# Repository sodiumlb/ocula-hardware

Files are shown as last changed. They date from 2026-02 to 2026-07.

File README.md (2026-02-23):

# ocula-hardware
Hardware design files for the Oric OCULA ULA replacement project.

## Related projects
[User Documentation](https://github.com/sodiumlb/ocula-docs)
[Firmware](https://github.com/sodiumlb/ocula-pivic-firmware)

## Important notes
OCULA hardware has been designed for low cost assembled production. It is not recommended to attempt manual assembly of anything other than through-hole components (headers, connectors).

Currently only OCULA-is-the-RAM mode is supported by the firmware, which means 2 mux-bridges are required for normal operation. The Micro DVI adapter and cable is optional.

## Main OCULA PCB
See pcb directory for design files for PCB production and PCBA of all surface mounted components. Due to very low clearance inside Oric-1 and Atmos cases, it is recommended to use stacking pin-headers to create flat pins on OCULA to allow low-profile mounting in machines with sockets.

## Mux bridges
The mux bridges use thin PCBs - 0.6mm is the only tested PCB thickness. The 3D printed snap-on frame will require modification if the PCB is different. The mux bridge modification is extremely simple and other solutions can be created. The effort put into this particular mux bridge design is to allow non-destructive but reliable modification of the Oric most people can use.

The current design is best assembled by first snapping the PCB into the 3D printed frame, then soldering in the 8 required pins. Thin, flat, flexible pins are needed here to make good contact with the mux ICs, thus it is recommended making these from the same stacking pin-headers as for the OCULA pins. Take care not to apply too much heat or use too long time, the 3D printed snap-on-frame will warp easily.

## Micro DVI adapter
The micro DVI adapter is optional. See the dvi-micro-adapter for PCB and 3D print adapter design files. The required cable spec is FFC, 20cm, 20pin, 0.5mm pitch, reverse direction (contacts are on opposing side on each end).

The 3D printed Oric adapter is designed to fit in place of the RF modulator. To secure the adapter, a longer screw is needed in place of the original PCB mounting screw fitted next to the RF modulator.

## Using stacking pin row headers to create IC pins
While there are many options for adding IC pins to PCBs, the solution that has provided the best low-cost way to get close to compatible with original IC pins, is to create them from long pinned PCB stacking headers. These have flat pins in a more spring-like metal that serves this alternative application well. 

This example shows 1x20 row 11mm stacking pin row headers.  
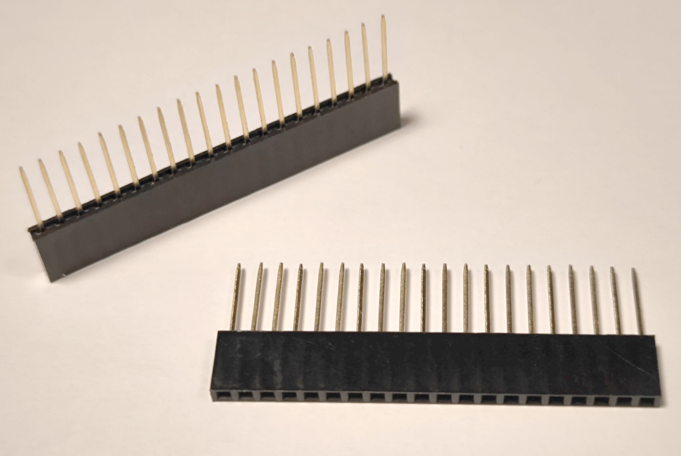
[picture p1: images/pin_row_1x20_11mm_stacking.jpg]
Example stacking pin headers

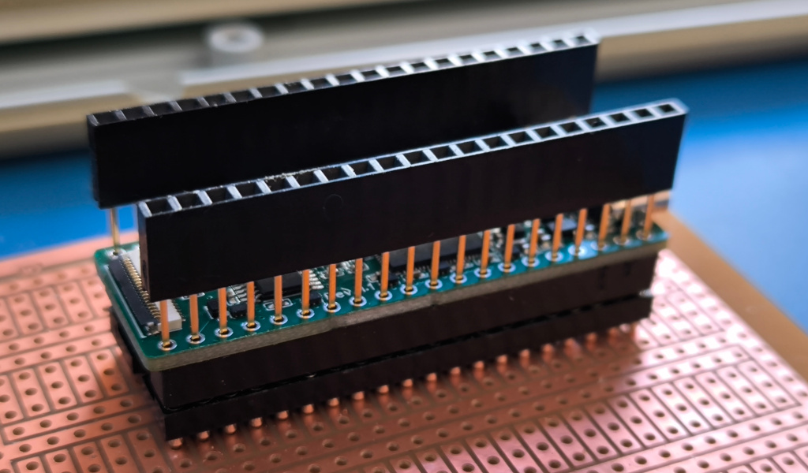
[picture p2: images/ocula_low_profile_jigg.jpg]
OCULA low-profile pin jigg

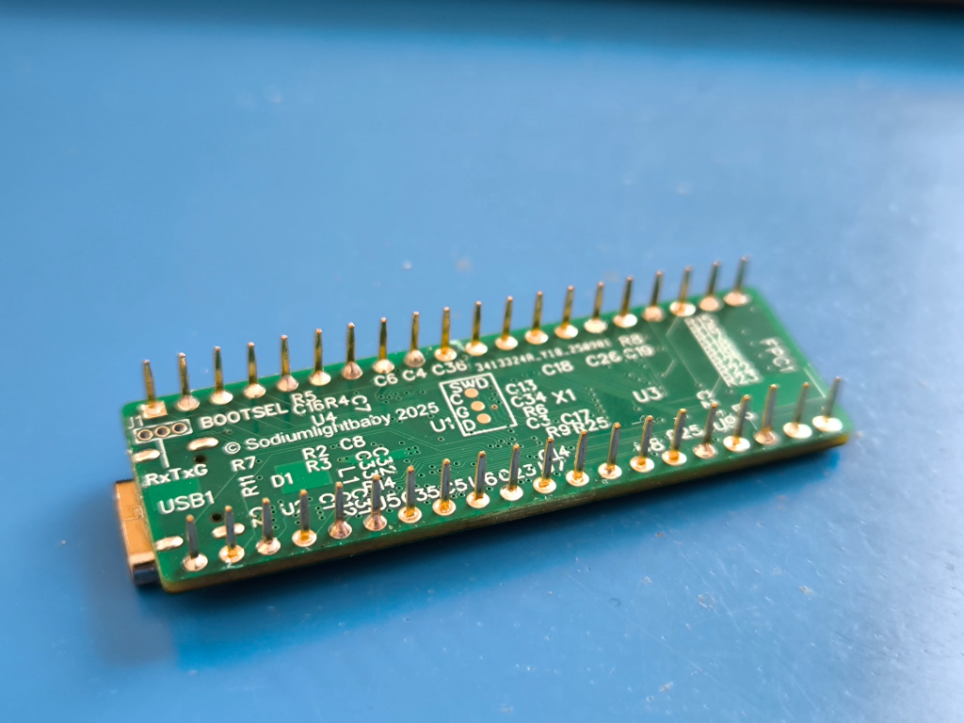
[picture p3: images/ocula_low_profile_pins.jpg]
OCULA low-profile pins

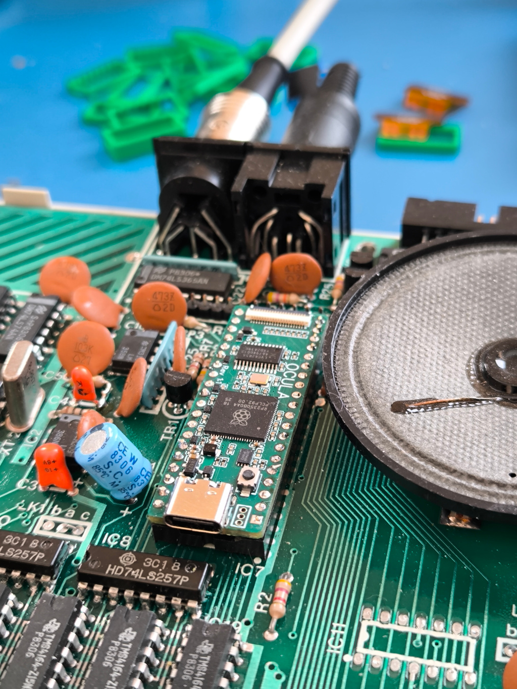
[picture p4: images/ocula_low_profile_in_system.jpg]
OCULA low-profile mounted in system


# Disclaimer
OCULA is an open source project by and for Oric users. It is provided AS-IS. For more information see each sub-project license agreement.

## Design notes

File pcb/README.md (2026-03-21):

# OCULA PCB Notes
The PCB package consists of EasyEDA SCH schematics and PCB board design source files, and Gerber, BOM and PickAndPlace production files for PCBA.

## BOM Notes
The following components are intentionally excluded from the BOM
1. J1 - Serial debug terminal header. Not needed for normal use
2. R4 - Flash pull-up resistor. A 10k pull-up may be needed for different flash chips.
3. IC1 - The ULA DIP-40 pin layout. IC pin substitues (pin-headers) must be installed manually after PCBA.

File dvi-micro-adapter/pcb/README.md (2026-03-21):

# Micro DVI Adapter
This FFC cable adapter is electrically compatible with both OCULA and PIVIC, and physically designed for integration in place of the Oric RF modulator together with the 3D printed adapter.

## BOM Notes
Be ware of additional X-Ray services can be added to the PCBA cost due to the pin placement on the Micro-HDMI style connector.
The alternative BOM with a substitue display connector is provided trading off component cost against service cost.

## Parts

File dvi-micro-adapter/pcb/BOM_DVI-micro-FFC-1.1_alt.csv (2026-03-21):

ID | Name | Designator | Footprint | Quantity | Manufacturer Part | Manufacturer | Supplier | Supplier Part | Price
1 | HDMI-101S | CN1 | HDMI-SMD_HDMI-101S | 1 | HDMI-101S | XUNPU(讯普) | LCSC | C720620 | 0.585
2 | HC-FPC-05-10-20RLTAG | FPC1 | FPC-SMD_20P-P0.50_HCTL_HC-FPC-05-10-20RLTAG | 1 | HC-FPC-05-10-20RLTAG | HCTL(华灿天禄) | LCSC | C5213737 | 0.182

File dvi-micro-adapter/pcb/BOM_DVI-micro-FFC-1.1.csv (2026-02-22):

ID | Name | Designator | Footprint | Quantity | Manufacturer Part | Manufacturer | Supplier | Supplier Part | Price
1 | HYC23-HDMID19-650 | CN1 | AUDIO-TH_HYC23-HDMID19-650 | 1 | HYC23-HDMID19-650 | 华宇创 | LCSC | C711358 | 0.367
2 | HC-FPC-05-10-20RLTAG | FPC1 | FPC-SMD_20P-P0.50_HCTL_HC-FPC-05-10-20RLTAG | 1 | HC-FPC-05-10-20RLTAG | HCTL(华灿天禄) | LCSC | C5213737 | 0.135

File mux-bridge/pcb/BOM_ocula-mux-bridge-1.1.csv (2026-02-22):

ID | Name | Designator | Footprint | Quantity | Manufacturer Part | Manufacturer | Supplier | Supplier Part | Price
1 | 4.7kΩ | R1,R2,R3,R4 | R0805 | 4 | 0805W8F4701T5E | UNI-ROYAL(厚声) | LCSC | C17673 | 0.002

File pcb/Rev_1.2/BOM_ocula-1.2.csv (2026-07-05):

ID | Name | Designator | Footprint | Quantity | Manufacturer Part | Manufacturer | Supplier | Supplier Part | Price
1 | BSS138W_C28646265 | Q1 | SOT-323-3_L2.1-W1.3-P1.30-LS2.3-BR | 1 | BSS138W | R+O(宏嘉诚) | LCSC | C28646265 | 0.024
2 | 100n | C4,C5,C6,C7,C8,C9,C13,C14,C16,C23,C24,C25,C26,C34,C35,C36 | C0402 | 16 | CL05B104KO5NNNC | SAMSUNG(三星) | LCSC | C1525 | 0.005
3 | SN74LVC2G17DCKR(UMW) | U5,U6,U7,U8 | SC-70-6_L2.2-W1.3-P0.65-LS2.1-TL | 4 | SN74LVC2G17DCKR(UMW) | UMW(友台半导体) | LCSC | C7394022 | 0.054
4 | 33Ω | R2,R3,R14 | R0402 | 3 | 0402WGF330JTCE | UNI-ROYAL(厚声) | LCSC | C25105 | 0.006
5 | TS-1088-AR02016 | SW1 | SW-SMD_L3.9-W3.0-P4.45 | 1 | TS-1088-AR02016 | XUNPU(讯普) | LCSC | C720477 | 0.056
6 | 1N5819WS | D1,D2 | SOD-323_L1.8-W1.3-LS2.5-RD | 2 | 1N5819WS | Hottech(合科泰) | LCSC | C191023 | 0.014
7 | HC-FPC-05-10-20RLTAG | FPC1 | FPC-SMD_20P-P0.50_HCTL_HC-FPC-05-10-20RLTAG | 1 | HC-FPC-05-10-20RLTAG | HCTL(华灿天禄) | LCSC | C5213737 | 0.192
8 | 220Ω | R15,R16,R17,R18,R19,R21,R22,R23 | R0402 | 8 | 0402WGF2200TCE | UNI-ROYAL(厚声) | LCSC | C25091 | 0.002
9 | ZD25WQ16CEIGR | U4 | USON-8_L3.0-W2.0-P0.50-BL-EP | 1 | ZD25WQ16CEIGR | Zetta(澜智) | LCSC | C7304007 | 0.332
10 | AOTA-B201610S3R3-101-T | L1 | IND-SMD_L2.0-W1.6_AOTA-B201610S3R3-101-T | 1 | AOTA-B201610S3R3-101-T | ABRACON | LCSC | C42411119 | 0.283
11 | RP2350B_C9900138392 | U1 | QFN-80_L10.0-W10.0-P0.40-TL-EP3.4 | 1 | RP2350B | Raspberry Pi | LCSC | C42415655 | 1.261
12 | 4.7uF | C3,C31,C32,C33 | C0402 | 4 | CL05A475MP5NRNC | SAMSUNG(三星) | LCSC | C23733 | 0.059
13 | 15pF | C17,C18 | C0402 | 2 | 0402CG150J500NT | FH(风华) | LCSC | C1548 | 0.009
14 | 5k1 | R7,R11 | R0402 | 2 | 0402WGF5101TCE | UNI-ROYAL(厚声) | LCSC | C25905 | 0.001
15 | ABM8-272-T3_C20625731 | X1 | CRYSTAL-SMD_4P-L3.2-W2.5-BL | 1 | ABM8-272-T3 | ABRACON | LCSC | C20625731 | 0.295
16 | 1uF | C1,C2 | C0603 | 2 | CL10A105KB8NNNC | SAMSUNG(三星) | LCSC | C15849 | 0.132
17 | XC6206P332MR | U2 | SOT-23-3_L2.9-W1.6-P1.90-LS2.8-BR | 1 | XC6206P332MR-G | TOREX(特瑞仕) | LCSC | C5446 | 0.118
18 | 1k | R5,R6 | R0402 | 2 | 0402WGF1001TCE | UNI-ROYAL(厚声) | LCSC | C11702 | 0.005
19 | 10k | R9 | R0402 | 1 | 0402WGF1002TCE | UNI-ROYAL(厚声) | LCSC | C25744 | 0.004
20 | TYPEC-304-ACP16 | USB1 | USB-C-SMD_TYPE-C-16P-1 | 1 | TYPEC-304-ACP16 | XUNPU(讯普) | LCSC | C2982555 | 0.156

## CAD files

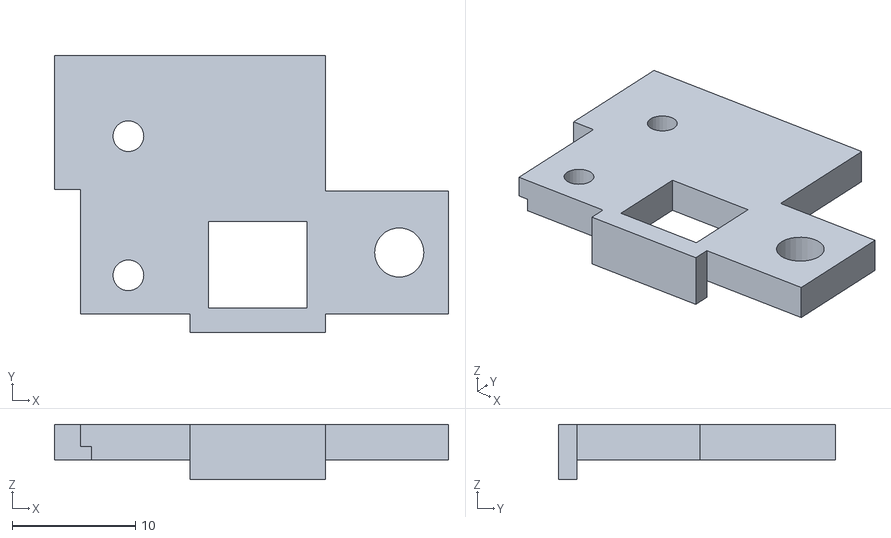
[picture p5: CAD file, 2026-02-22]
dvi-micro-adapter/oric_adapter/ocula_pivic_micro_dvi_adapter_full-BodyBottom.stl
32.0 x 22.5 x 4.50

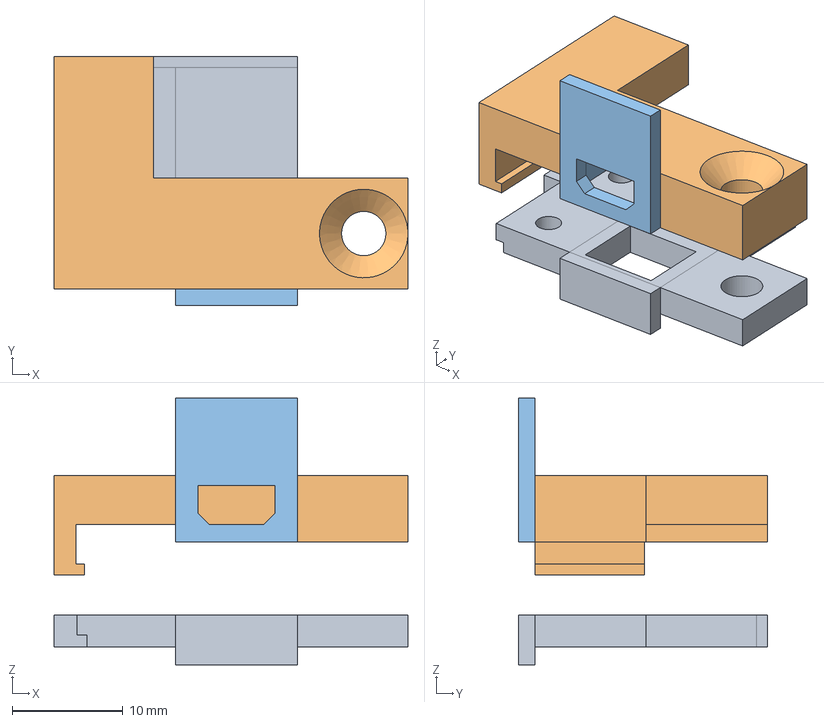
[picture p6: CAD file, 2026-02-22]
dvi-micro-adapter/oric_adapter/ocula_pivic_micro_dvi_adapter_full.FCStd
32.0 x 22.5 x 24.1 mm
BodyBottom
BodyTop
BodyFace

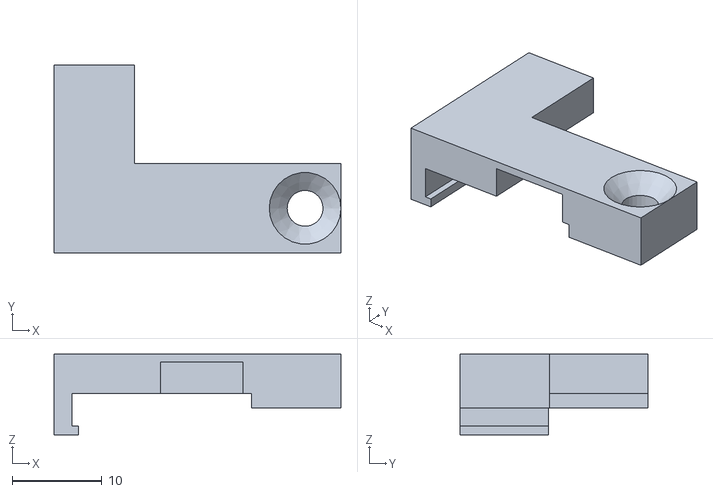
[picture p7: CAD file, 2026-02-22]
dvi-micro-adapter/oric_adapter/ocula_pivic_micro_dvi_adapter_full-BodyTop.stl
32.0 x 21.0 x 9.00

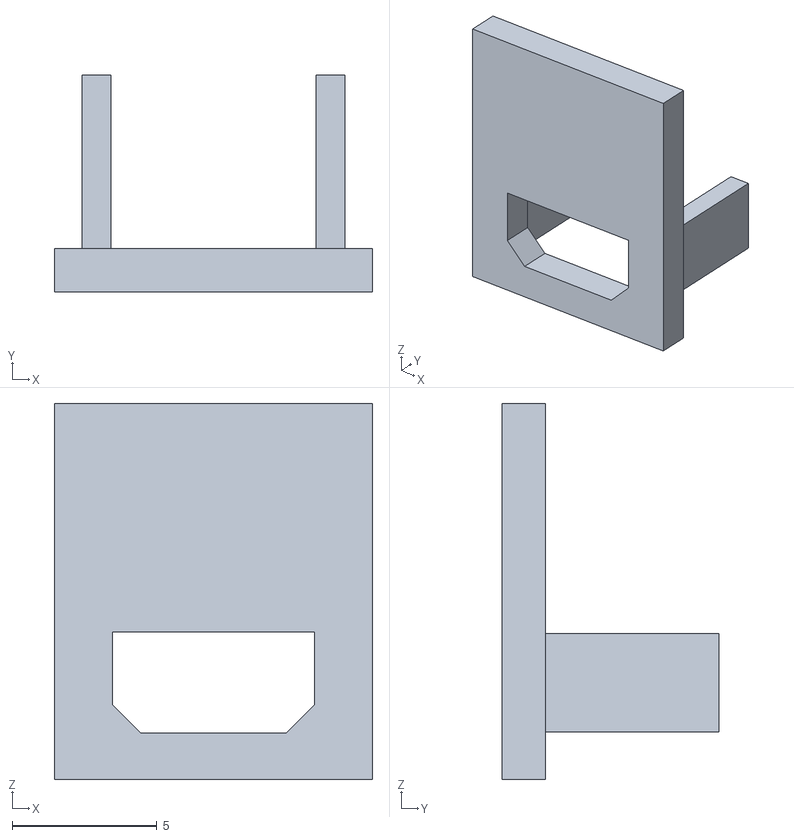
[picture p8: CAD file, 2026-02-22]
dvi-micro-adapter/oric_adapter/ocula_pivic_micro_dvi_adapter_full-BodyFace.stl
11.0 x 7.50 x 13.0

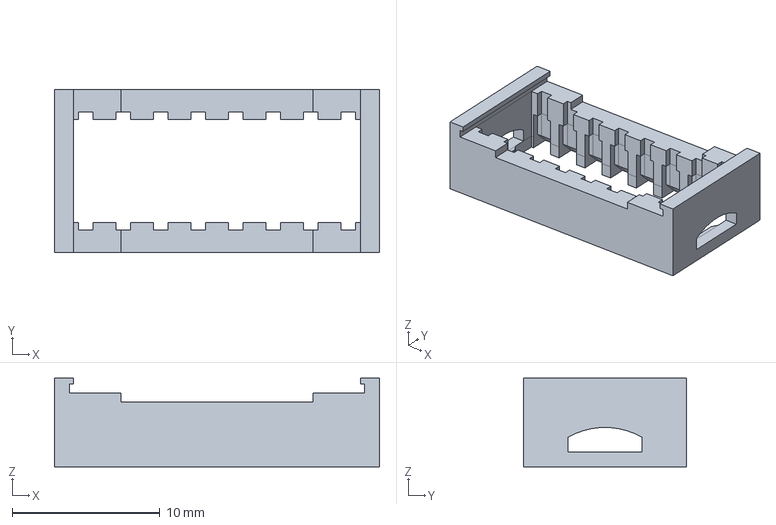
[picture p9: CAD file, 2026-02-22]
mux-bridge/clip-on-frame/dip-16-mux-bridge.FCStd
22.0 x 11.0 x 6.00 mm

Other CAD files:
mux-bridge/clip-on-frame/dip-16-mux-bridge-Body.stl

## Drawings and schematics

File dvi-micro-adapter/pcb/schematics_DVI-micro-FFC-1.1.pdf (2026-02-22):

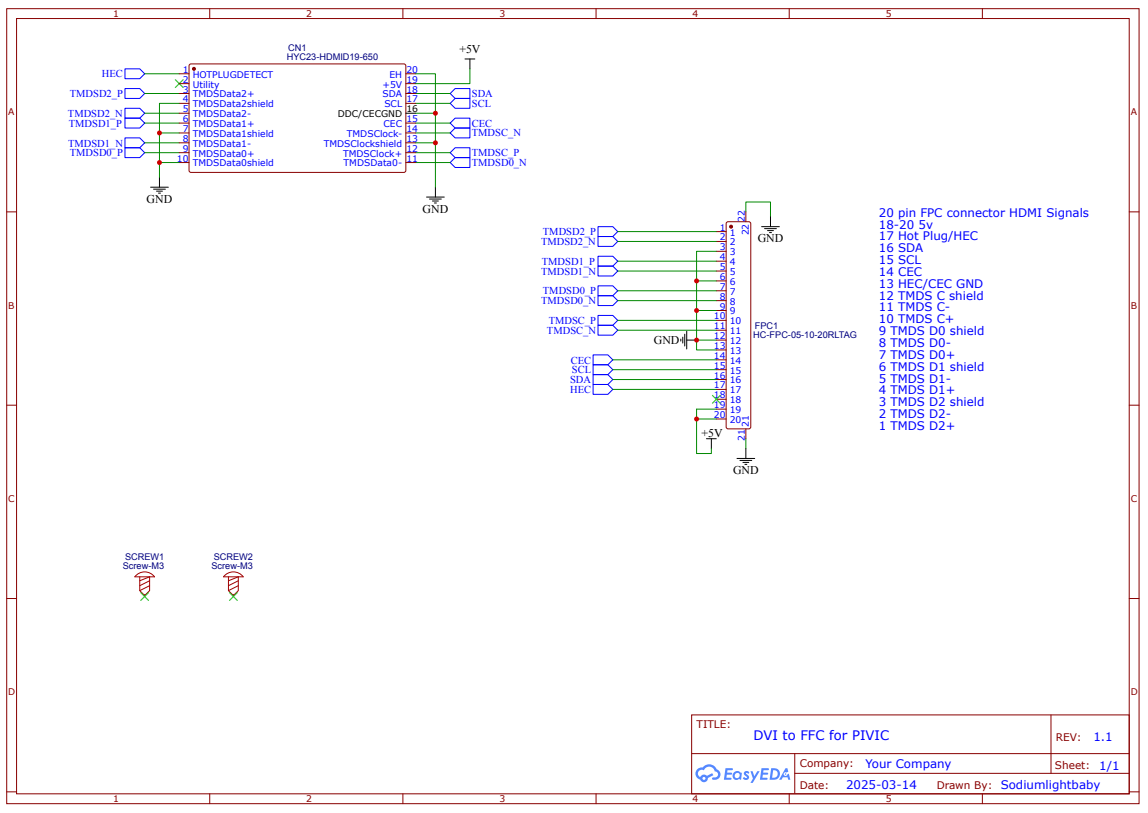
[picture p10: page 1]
TITLE:; DVI to FFC for PIVIC; REV: 1.1; Date:; Sheet: 1/1; TMDSC_P; TMDSD0_N; GND; HC-FPC-05-10-20RLTAG; FPC1; TMDSC_N; TMDSD0_P; TMDSD1_P TMDSD1_N; TMDSD2_N; TMDSD2_P; HEC; SDA; SCL; CEC; TMDSD1_N; TMDSD1_P; Screw-M3; SCREW1; SCREW2; HYC23-HDMID19-650; HOTPLUGDETECT 1 Utility 2 TMDSData2+ 3 TMDSData2shield 4 TMDSData2- 5 TMDSData1+ 6 TMDSData1shield 7 TMDSData1- 8 TMDSData0+ 9; TMDSData0shield 10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

20 pin FPC connector HDMI Signals
17 Hot Plug/HEC
16 SDA
15 SCL
14 CEC
13 HEC/CEC GND
12 TMDS C shield
11 TMDS C-
10 TMDS C+
9 TMDS D0 shield
8 TMDS D0-
7 TMDS D0+
6 TMDS D1 shield
5 TMDS D1-
4 TMDS D1+
3 TMDS D2 shield
2 TMDS D2-
1 TMDS D2+

Company: Your Company

Drawn By: Sodiumlightbaby

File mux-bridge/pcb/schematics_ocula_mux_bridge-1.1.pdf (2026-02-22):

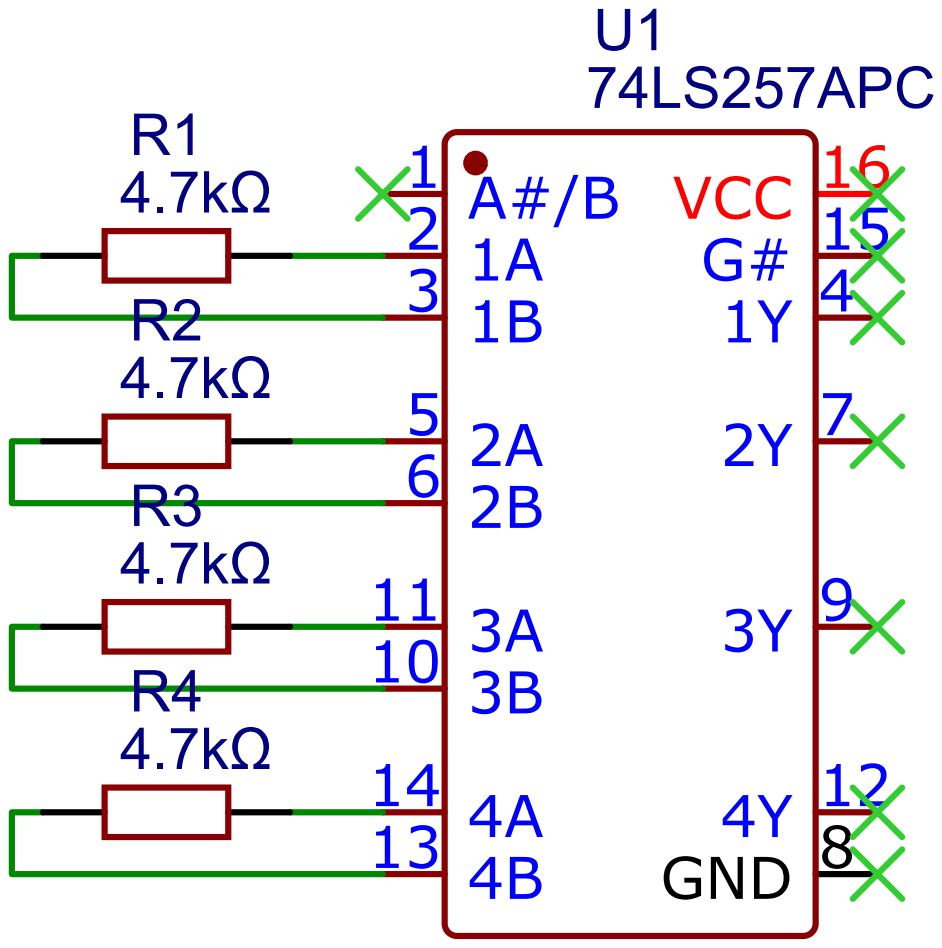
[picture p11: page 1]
TITLE:; Sheet_1; REV: 1.1; Date:; Sheet: 1/1; 74LS257APC; VCC 16 G# 15; GND 8

Company: Your Company

Drawn By: Sodiumlightbaby

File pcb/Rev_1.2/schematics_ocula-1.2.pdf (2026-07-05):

GPIO47_ADC7 58 GPIO46_ADC6 57 GPIO45_ADC5 56 GPIO44_ADC4 55 GPIO43_ADC3 54 GPIO42_ADC2 53 GPIO41_ADC1 52 GPIO40_ADC0 49 GPIO39 48 GPIO38 47 GPIO37 46 GPIO36 45 GPIO35 44 GPIO34 43 GPIO33 42 GPIO32 40 GPIO31 39 GPIO30 38 GPIO29 37 GPIO28 36 GPIO27 28 GPIO26 27 GPIO25 26 GPIO24 25 GPIO23 23 GPIO22 22 GPIO21 21 GPIO20 20 GPIO19 19 GPIO18 18 GPIO17 17 GPIO16 16 GPIO15 14 GPIO14 13 GPIO13 12 GPIO12 11 GPIO11 9 GPIO10 8 GPIO9 7 GPIO8 6 GPIO7 4 GPIO6 3 GPIO5 2 GPIO4 1 GPIO3 80 GPIO2 79 GPIO1 78 GPIO0 77

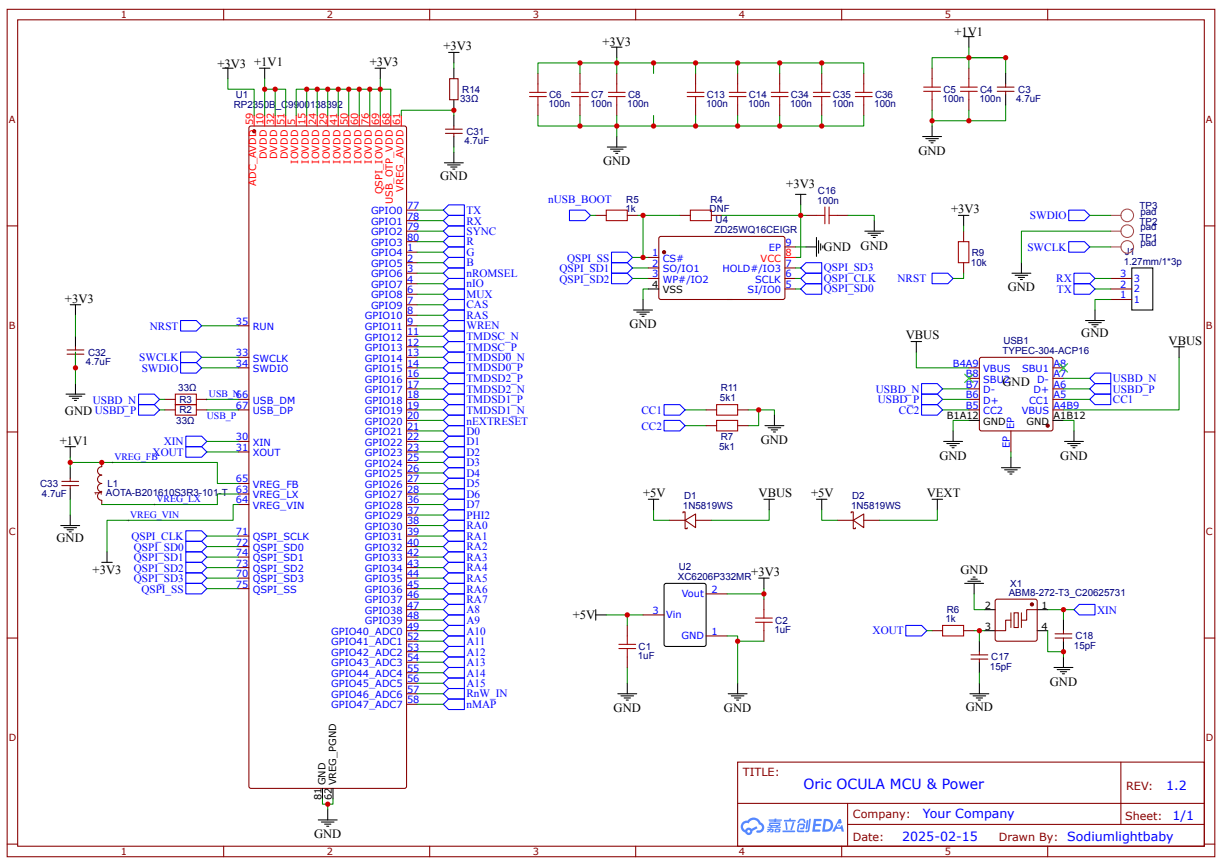
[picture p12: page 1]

VREG_AVDD 61 USB_OTP_VDD 68 QSPI_IOVDD 69 IOVDD 76 IOVDD 60 IOVDD 50 IOVDD 41

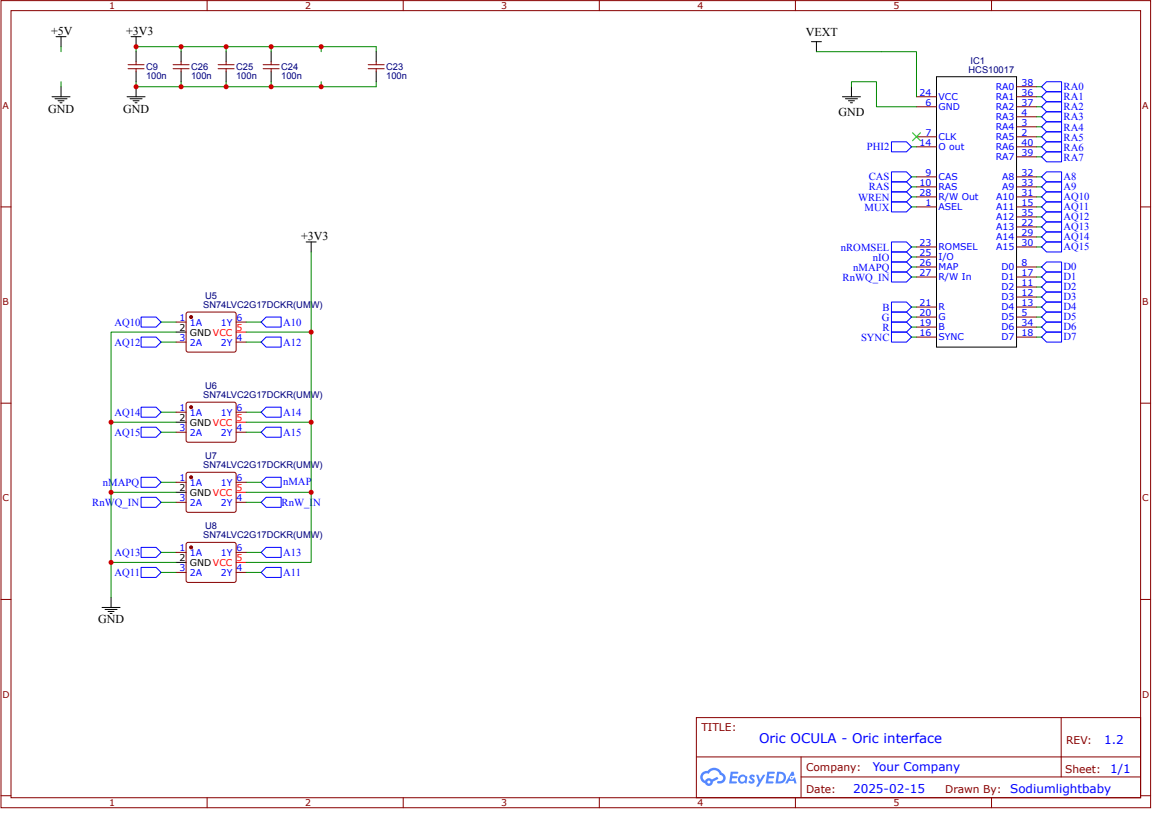
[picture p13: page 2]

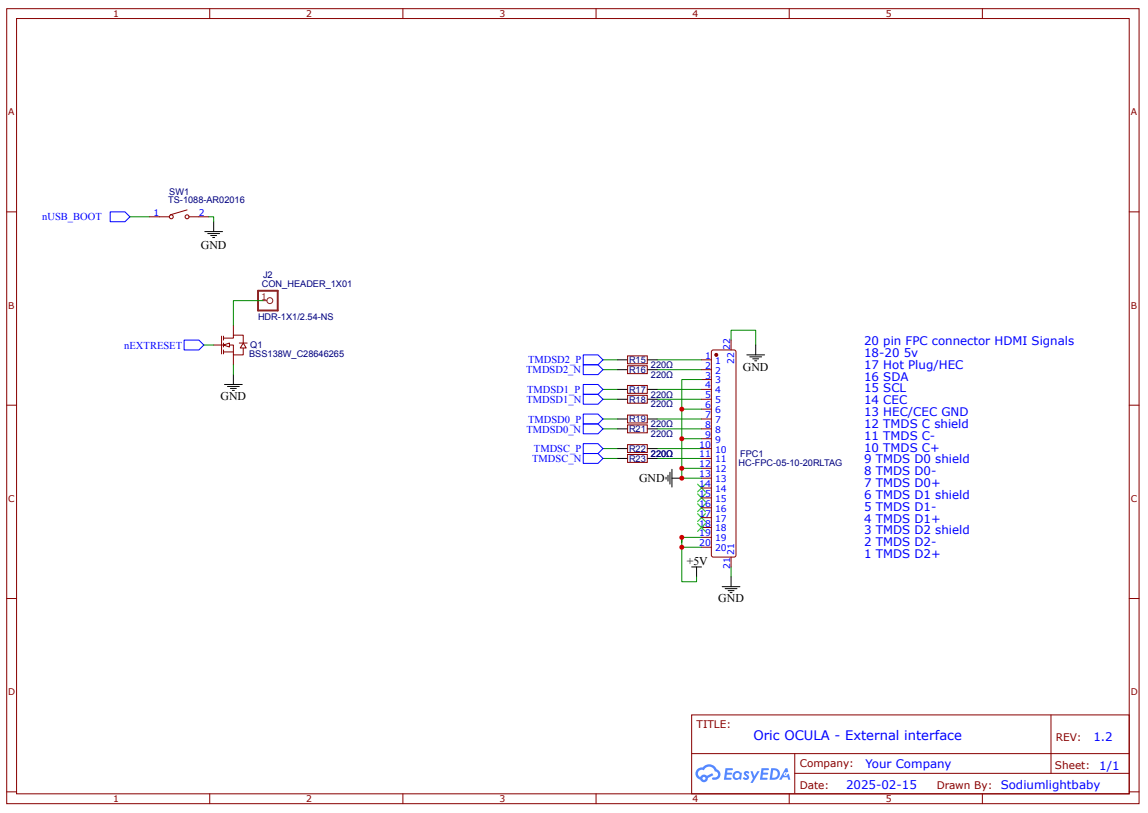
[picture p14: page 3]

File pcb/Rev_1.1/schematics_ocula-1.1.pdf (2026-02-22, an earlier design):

GPIO47_ADC7 58 GPIO46_ADC6 57 GPIO45_ADC5 56 GPIO44_ADC4 55 GPIO43_ADC3 54 GPIO42_ADC2 53 GPIO41_ADC1 52 GPIO40_ADC0 49 GPIO39 48 GPIO38 47 GPIO37 46 GPIO36 45 GPIO35 44 GPIO34 43 GPIO33 42 GPIO32 40 GPIO31 39 GPIO30 38 GPIO29 37 GPIO28 36 GPIO27 28 GPIO26 27 GPIO25 26 GPIO24 25 GPIO23 23 GPIO22 22 GPIO21 21 GPIO20 20 GPIO19 19 GPIO18 18 GPIO17 17 GPIO16 16 GPIO15 14 GPIO14 13 GPIO13 12 GPIO12 11 GPIO11 9 GPIO10 8 GPIO9 7 GPIO8 6 GPIO7 4 GPIO6 3 GPIO5 2 GPIO4 1 GPIO3 80 GPIO2 79 GPIO1 78 GPIO0 77

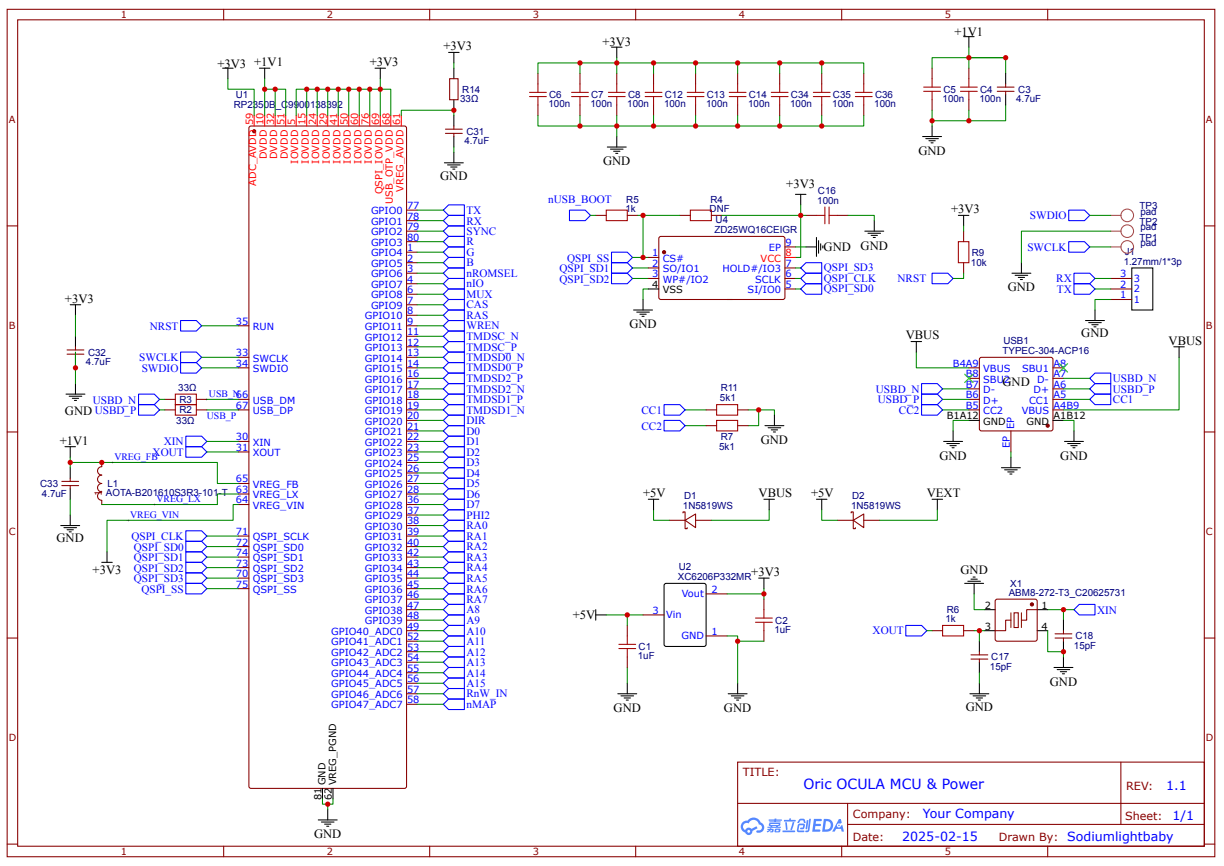
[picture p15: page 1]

VREG_AVDD 61 USB_OTP_VDD 68 QSPI_IOVDD 69 IOVDD 76 IOVDD 60 IOVDD 50 IOVDD 41

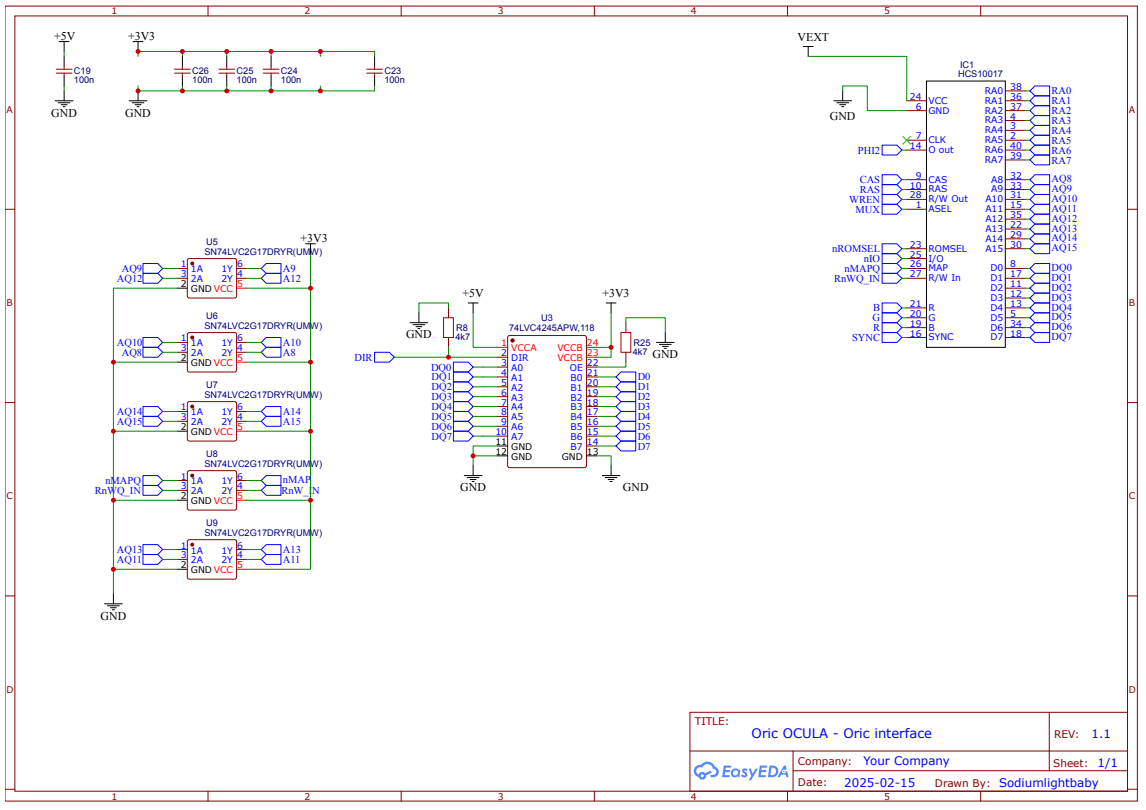
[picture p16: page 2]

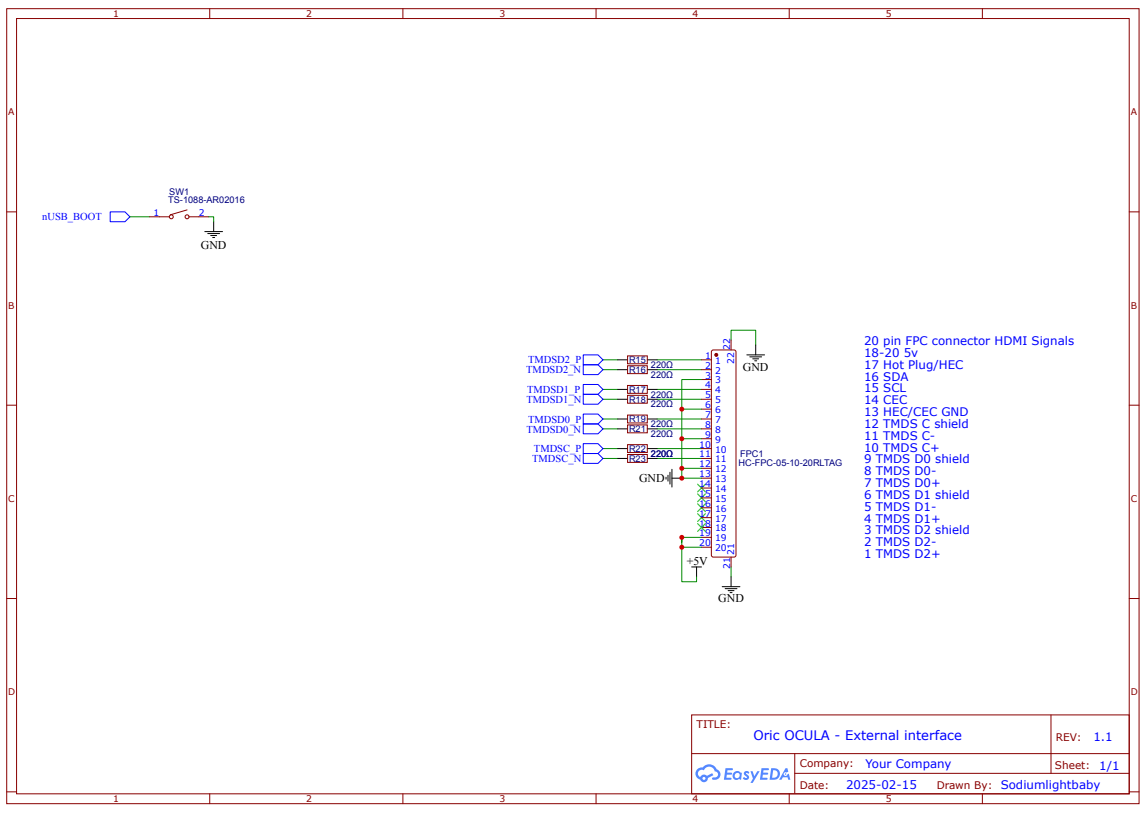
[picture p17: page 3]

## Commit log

2026-02-22 Initial hardware design files
    [BOM_DVI-micro-FFC-1.1.csv, BOM_ocula-1.1.csv, BOM_ocula-mux-bridge-1.1.csv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]
2026-03-21 Add missing PCB file
2026-03-21 Add missing PCB source file
2026-03-21 Add alternative BOM
    [BOM_DVI-micro-FFC-1.1_alt.csv]
2026-07-05 Move PCB Rev_1.1 files to own directory
    [BOM_ocula-1.1.csv, PickAndPlace_PCB_ocula_1.1.csv]
2026-07-05 Add PCB Rev 1.2 files
    [BOM_ocula-1.2.csv, PickAndPlace_PCB_ocula_1.2.csv]
